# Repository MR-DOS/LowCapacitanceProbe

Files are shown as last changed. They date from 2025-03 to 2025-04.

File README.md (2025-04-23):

# LowCapacitanceProbe

## THIS DESIGN IS STILL UNDER CONSTRUCTION, ANY EXPORTED DATA ARE NON-FINAL AND ARE LIKELY NOT TO WORK. DO NOT ATTEMPT TO BUILD THIS DEVICE UNTIL THIS NOTICE DISAPPEARS! ALL IMAGES ARE PLACEHOLDERS AND MAY NOT FULLY REPRESENT THE REAL DEVICE AND MAY BE OUT OF SYNC WITH THE DESIGN DATA!

## USABLE DATA WILL BE PRESENT IN RELEASES TAB.

## 1+ GHz AC Probe with low input capacitance (less than 1 pF, hopefully)

2 dB flatness should be approx. 1.6 GHz, 3 dB flatness should be about 2.1 GHz, 6 dB flatness should be about 3.3 GHz. Design needs to be verified in reality (simulation is likely over-optimistic). In-band flatness should be better than 0.2 dB. Lower 6 dB corner should be at about 30 kHz while 3 dB corner is at about 50 kHz. The design should have fairly low noise, at least above 1 MHz.

Drawn in KiCAD 9.0.x, simulated in LTspice 17.x / 24.x.

## Expected issues

* Large noise at < 1 MHz due to thermal noise of 1M bias resistor
* Incorrect impedance of 50R traces
* Incorrect output impedance
* Possible instability of BF998 / spectrum peaking
* Bad linearity, especially due to use of varactor and resistor instead of current sink in source of BF998
* Large variance of parameters due to use of BF998

## Known issues which will be present

* No box yet (has to be covered in conductive material)
* Usage of obsolete part which is difficult to obtain (BF998)
* Component values not tried, will be suboptimal
* Varactor will probably need to be changed
* Needed manual calibration using a VNA and some tools
* Potentiometers not delinearised yet

## Board images (rendered)

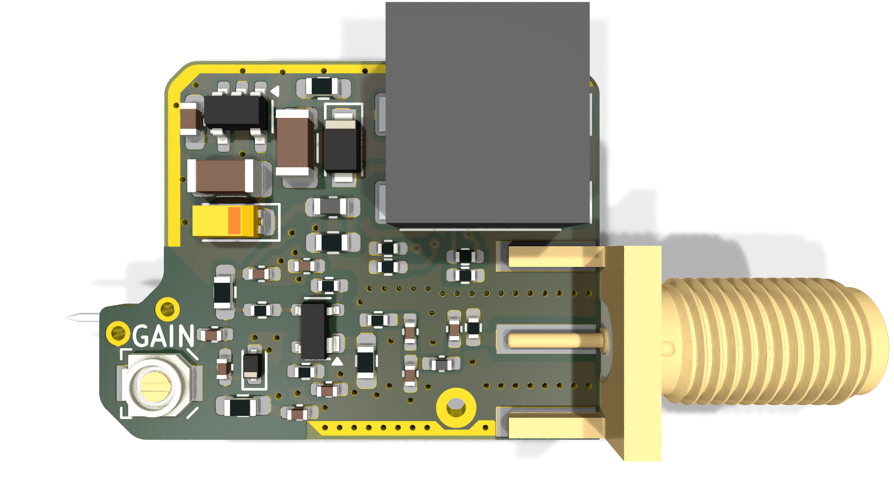
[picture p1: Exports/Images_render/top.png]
Board image TOP


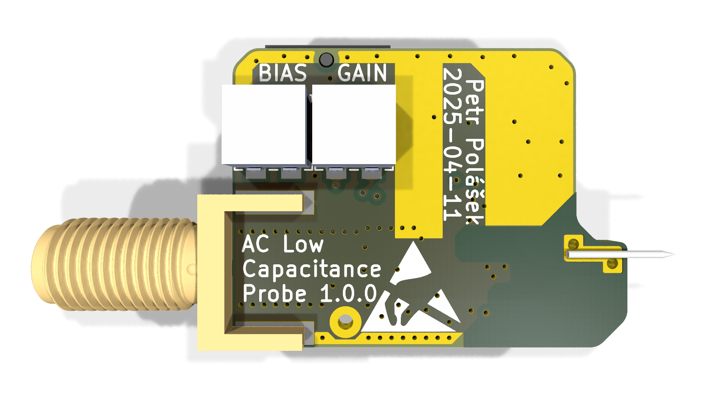
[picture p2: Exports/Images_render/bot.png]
Board image BOT


## Live on-line project browser

[KiCanvas project viewer, disable layer Dwgs.User, view is not 1:1 with KiCAD](https://kicanvas.org/?github=https%3A%2F%2Fgithub.com%2FMR-DOS%2FLowCapacitanceProbe%2Ftree%2Fmain)

## Schematic

[Schematic SVG](https://github.com/MR-DOS/LowCapacitanceProbe/raw/main/Exports/Schematic/LowCapacitanceProbe.svg)

[Schematic PDF](https://github.com/MR-DOS/LowCapacitanceProbe/raw/main/Exports/Schematic/LowCapacitanceProbe.pdf)

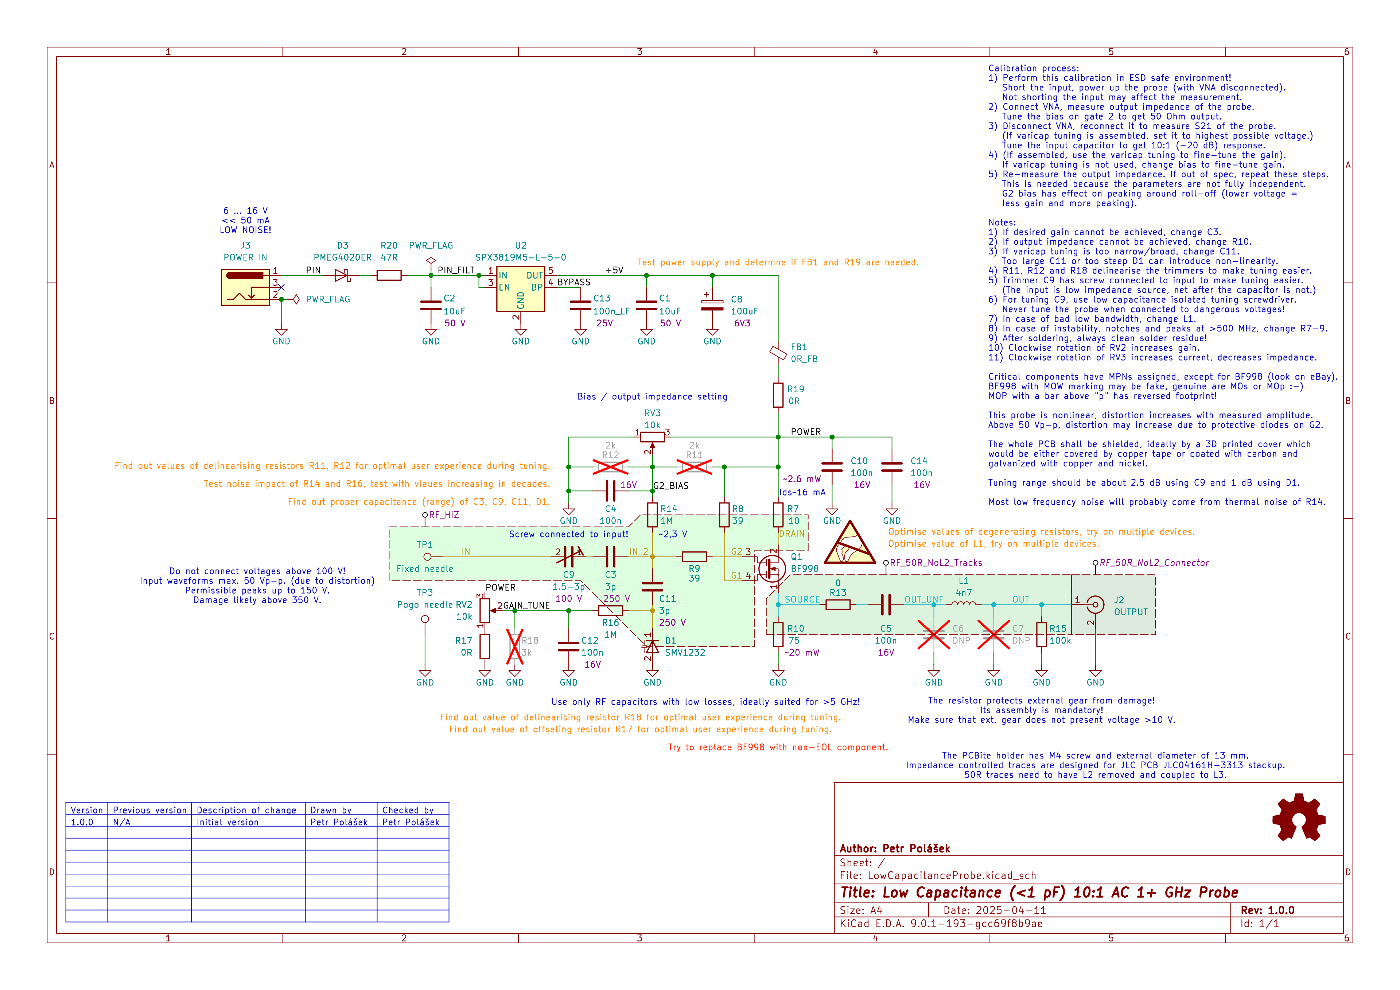
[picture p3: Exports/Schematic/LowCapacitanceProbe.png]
Schematic PNG, decent resolution


## PCB drawing image

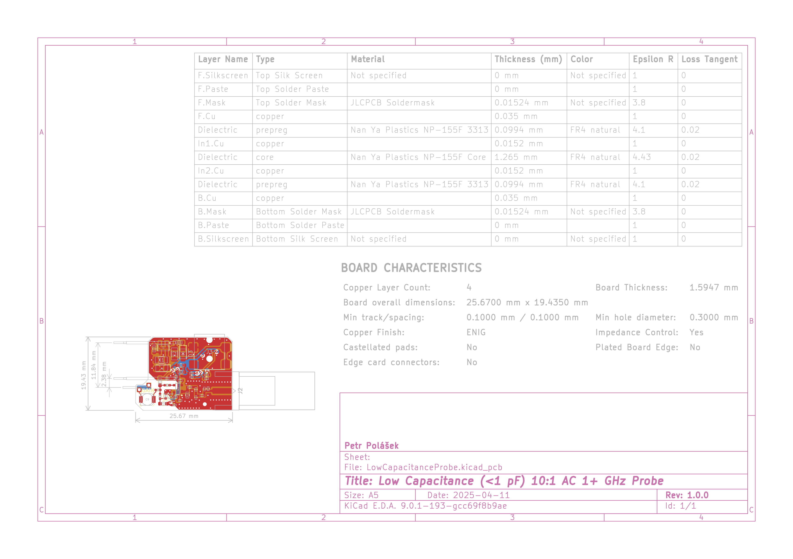
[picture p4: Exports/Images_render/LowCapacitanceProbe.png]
PCB drawing image


## 3D models

[STEP with solder mask, pads and copper fills (save to view)](https://github.com/MR-DOS/LowCapacitanceProbe/raw/main/Exports/3D/board.step)

[Simplified STEP (save to view)](https://github.com/MR-DOS/LowCapacitanceProbe/raw/main/Exports/3D/simplified/simplified.step)

## Board Shape

[DXF with board shape (save to view)](https://github.com/MR-DOS/LowCapacitanceProbe/raw/main/Exports/DXF/LowCapacitanceProbe-Edge_Cuts.dxf)

## Gerbers for production

[Zipped Gerbers](https://github.com/MR-DOS/LowCapacitanceProbe/raw/main/Exports/Gerbers/ZIP/LowCapacitanceProbe_v1.0.0.zip)

[Non-zipped Gerbers](https://github.com/MR-DOS/LowCapacitanceProbe/raw/main/Exports/Gerbers/)

## BOM

[Interactive BOM (save to view)](https://github.com/MR-DOS/LowCapacitanceProbe/raw/main/Exports/BOM/LowCapacitanceProbe_Interactive_BOM.html)

[CSV BOM (save to view)](https://github.com/MR-DOS/LowCapacitanceProbe/raw/main/Exports/BOM/LowCapacitanceProbe.csv)

## Jobset for exporting data

Use [this jobset (download it to view)](https://github.com/MR-DOS/LowCapacitanceProbe/raw/main/Outputs.kicad_jobset) for your designs, it is somewhat tested and should produce usable data. You can recreate all exports present in this repo using it.

## Simulation

[Simulation comparing this design and the FETProbe_V2 design (download to view)](https://github.com/MR-DOS/LowCapacitanceProbe/raw/main/Simulation/probe.asc) which works in LTspice 17.x and LTspice 24.x. Please note that you HAVE TO use alternate solver instead of normal solver (Tools -> Control Panel -> SPICE -> Engine -> Solver). The normal solver is faster, but has some stability issues and returns "hairy" traces of simulated gain which cannot be explained from electrical/physical standpoint.

## Sources for this design

Forked from [FETProbe_V2](https://github.com/makerprobe/FETProbe_V2) by makerprobe which is an improved fork of crteensy's [FETProbe_tiny](https://github.com/crteensy/FETProbe_tiny). Some ideas are taken from the FETProbe_V2, but most of the core design was changed to allow precise gain tuning, also the original design was suffering from being near stability threshold (and thus probably required the "spike filter").

The probe is also somewhat similar to my older [E-field probe](https://hackaday.io/project/169611-simple-e-field-probe) (which was just an unfinished toy for sniffing around circuits contactless) which is older than crteensy's FETProbe, but used G1 instead of G2 of BF998.

The need for stabilising resistors was found in another, even older project of mine, the [cheap TDR](https://github.com/MR-DOS/TDR_diploma_thesis). BF998 in source follower mode is prone to oscillation, especially when high impedance of capacitive characteristic is connected to its input.

## Intention of this design

First of all - I wanted to try the new KiCAD 8 and 9. It is also a development tool to make and tune a reusable jobset, design rules and checklist for checking validity of design (will be published later).

This project will try to make some RF optimalizations, usability improvements as well as (maybe) ability to use higher frequency transistor CF-739. However, there is no simulation model for CF-739, so it will have to be optimised empirically (and manually). Also, it is discontinued (like the BF998) and hard to obtain, rendering it unusable for making more than a few pieces of this probe.

Another path for improvement is to try using a JFET whch is still in production (J3xx or 2N439x).

Ability to tune the device (gain, output impedance) will be made to allow precise operation without fiddling with replacing components.

## Plans for next versions

A JFET version is planned to be tested if a JFET can replace the BF998. Even though the BF998 are not difficult to obtain, they are obsolete.
JFET simulation [can be found here (download to view)](https://github.com/MR-DOS/LowCapacitanceProbe/raw/main/Simulation/probe_jfet.asc).

Several JFETs [were found to be similar](https://github.com/MR-DOS/LowCapacitanceProbe/raw/main/Simulation/jfet_sim_notes.txt) to the BF998 in simulation. However they need to be tested.

## Other notes

If you want to figure out where your BF998 was produced, [look here](http://sp7pki.iq24.pl/default.asp?grupa=3536&temat=449565).

Beware of buying BF998R, those have reversed pinout. Also do not buy ones marked as "WMO", those are also reversed AND in smaller package than normal. ("MOW" are OK)

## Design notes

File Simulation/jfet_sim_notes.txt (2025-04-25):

Sim notes:
2N4392 - slight problems getting to -20 dB
2N4393 - better by ~1 dB
2N5486 - -20 dB will likely need larger capacitance
J113	 - with difficulties -21 dB
LS5912C - -20 dB will likely need larger capacitance
LS5912 - maybe slightly better
LS5911 - similar
LS845  - -20 dB will likely need larger capacitance
PN4119 - slight problems getting to -20 dB
PN4118/7 - probably better
PN4393 - similar to 2N4393
SST440 - larger capacity needed

Winners:
PN4118 - slightly expensive, 3 pF
PN4117 - like 4118, lower current, 3 pF
2N4393 - THT only, 14 pF
PN4393 - THT only, 14 pF
LS5912 - expensive, dual, 5 pF

Ordered:
106-SMP4118A		2x
106-SMP4393			2x
610-CMPF4393TR-TIN	2x
863-MMBF4393LT1G		10x (cheap)
610-CMPF4392		2x
863-MMBF4392LT1G		10x (cheap)
512-MMBF4117		10x (cheap)

Further notes:
Models of JFETs now downloaded from here
https://www.interfet.com/jfet-spice-models/
https://www.interfet.com/jfet-datasheets/standard.jft
2N3970/1	NSC		-24 dB
2N5105	NSC		-24 dB
2N4391	Linear Sys	-22 dB
2N4856A	NSC		-21 dB
2N5486	Siliconix	-21 dB
2N4392/3	Linear Sys	-20 dB
PN4117/8	Linear Sys	-20 dB
PN4393	Linear Sys	-20 dB
PN4119	Linear Sys	-19.5 dB
2N4857A/8A	NSC		-19.5 dB
2N4860A	NSC		-19.5 dB
2N4861A	NSC		-19 dB
2N3824	InterFET	-18 dB
SSTJ212	Linear Sys	-10 dB

BF998 optimisation A:
G1	10
G2	56
D	42
L	4n7
BW1dB	3.9 GHz
BW3dB	4.3 GHz
BW6db	4.8 GHz
Peak	3 GHZ, +0.5 dB
Fall	20 dB/oct	

BF998 optimisation B:
G1	22
G2	51
D	42
L	3n3
BW1dB	3.4 GHz
BW3dB	4.1 GHz
BW6db	4.8 GHz
Peak	1.4 GHz, +0.08 dB
Fall	20 dB/oct

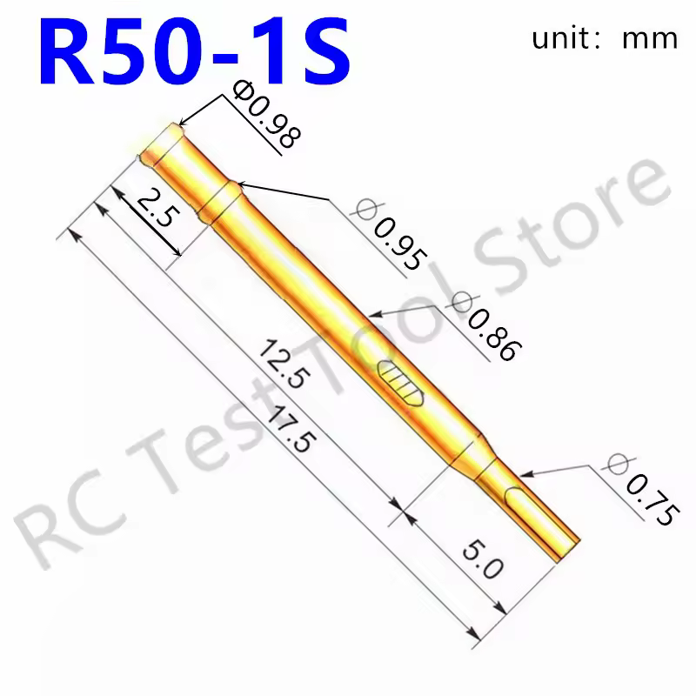
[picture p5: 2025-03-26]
Mechanical/R50-1S.png

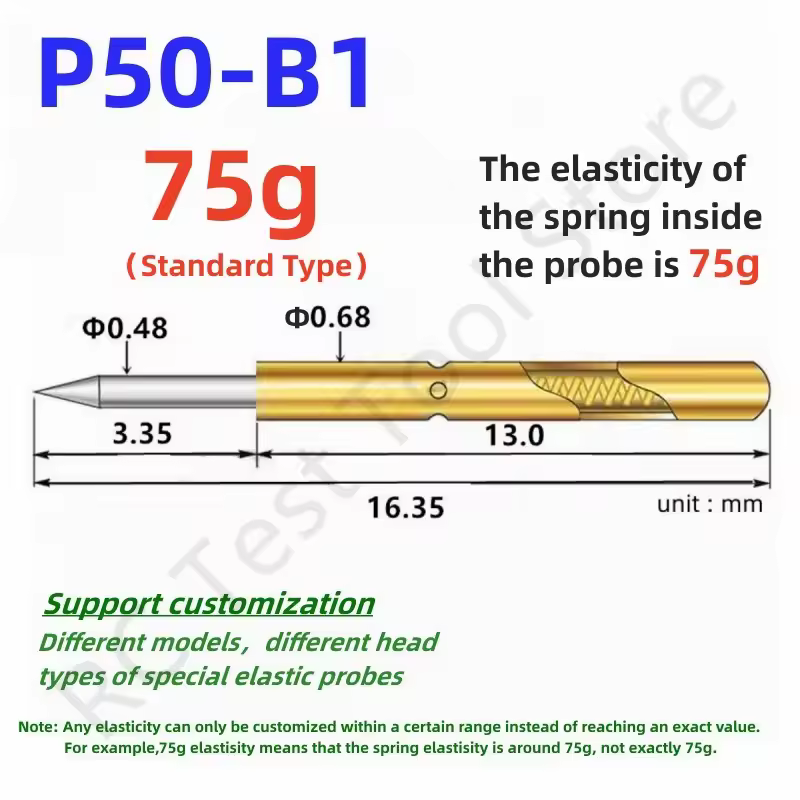
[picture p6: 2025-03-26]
Mechanical/P50-B1.png

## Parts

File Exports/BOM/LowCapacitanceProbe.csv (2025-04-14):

Reference | Value | Footprint | MPN | Mouser | Qty
C1,C2 | 10uF | Capacitor_SMD:C_1206_3216Metric | CL31A106MBHNNNE | 187-CL31A106MBHNNNE | 2
C3,C11 | 3p | Capacitor_SMD:C_0402_1005Metric_Pad0.74x0.62mm_HandSolder | 600F3R0CT250XT | 581-600F3R0CT | 2
C4,C5,C10,C12,C14 | 100n | Capacitor_SMD:C_0402_1005Metric_Pad0.74x0.62mm_HandSolder | 530L104KT16T | 581-530L104KT16T | 5
C6,C7 | DNP | Capacitor_SMD:C_0402_1005Metric_Pad0.74x0.62mm_HandSolder |  |  | 2
C8 | 100uF | Capacitor_Tantalum_SMD:CP_EIA-3216-18_Kemet-A | T55A107M6R3C0045 | 74-T55A107M6R3C0045 | 1
C9 | 1.5-3p | Capacitor_SMD:C_Trimmer_Voltronics_JR | JR030 | 768-JR030 | 1
C13 | 100n_LF | Capacitor_SMD:C_0603_1608Metric_Pad1.08x0.95mm_HandSolder |  |  | 1
D1 | SMV1232 | Diode_SMD:D_SOD-523 | SMV1231-079LF | 873-SMV1231-079LF | 1
D3 | PMEG4020ER | Diode_SMD:Nexperia_CFP3_SOD-123W | PMEG4020ER,115 | 771-PMEG4020ER115 | 1
FB1 | 0R_FB | Inductor_SMD:L_0603_1608Metric_Pad1.05x0.95mm_HandSolder |  |  | 1
J2 | OUTPUT | Connector_Coaxial:SMA_Amphenol_132289_EdgeMount | 132289 | 523-132289 | 1
J3 | POWER IN | Connector_BarrelJack:BarrelJack_Wuerth_694103107102_1.35x3.9mm | 694103107102 | 710-694103107102 | 1
L1 | 4n7 | Inductor_SMD:L_0402_1005Metric_Pad0.77x0.64mm_HandSolder | LQG15HS4N7B02D | 81-LQG15HS4N7B02D | 1
Q1 | BF998 | Package_TO_SOT_SMD:SOT-143 |  |  | 1
R7 | 10 | Resistor_SMD:R_0402_1005Metric_Pad0.72x0.64mm_HandSolder |  |  | 1
R8,R9 | 39 | Resistor_SMD:R_0402_1005Metric_Pad0.72x0.64mm_HandSolder |  |  | 2
R10 | 75 | Resistor_SMD:R_0603_1608Metric_Pad0.98x0.95mm_HandSolder |  |  | 1
R11,R12 | 2k | Resistor_SMD:R_0402_1005Metric_Pad0.72x0.64mm_HandSolder |  |  | 2
R13 | 0 | Resistor_SMD:R_0402_1005Metric_Pad0.72x0.64mm_HandSolder |  |  | 1
R14,R16 | 1M | Resistor_SMD:R_0603_1608Metric_Pad0.98x0.95mm_HandSolder |  |  | 2
R15 | 100k | Resistor_SMD:R_0402_1005Metric_Pad0.72x0.64mm_HandSolder |  |  | 1
R17,R19 | 0R | Resistor_SMD:R_0402_1005Metric_Pad0.72x0.64mm_HandSolder,Resistor_SMD:R_0603_1608Metric_Pad0.98x0.95mm_HandSolder |  |  | 2
R18 | 3k | Resistor_SMD:R_0402_1005Metric_Pad0.72x0.64mm_HandSolder |  |  | 1
R20 | 47R | Resistor_SMD:R_0603_1608Metric_Pad0.98x0.95mm_HandSolder |  |  | 1
RV2,RV3 | 10k | Potentiometer_SMD:Potentiometer_Bourns_3214J_Horizontal | 3214J-1-103E | 652-3214J-1-103E | 2
U2 | SPX3819M5-L-5-0 | Package_TO_SOT_SMD:SOT-23-5 | SPX3819M5-L-5-0/TR | 701-SPX3819M5-L-50TR | 1

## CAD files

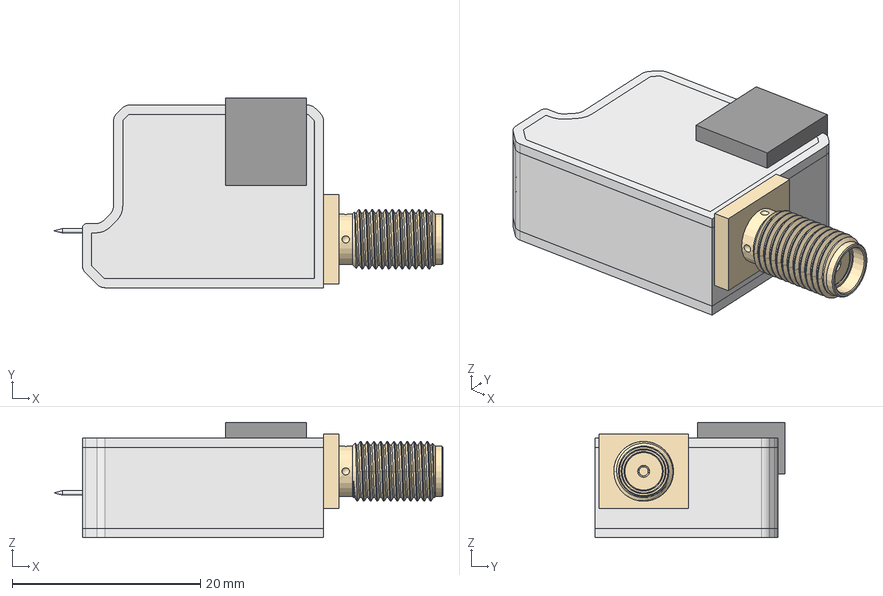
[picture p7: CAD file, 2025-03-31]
Mechanical/Assembly.FCStd
41.4 x 20.2 x 12.3 mm
SMA_Amphenol_132289_EdgeMount
C_0603_1608Metric
C_1206_3216Metric
3214J-1-103E
SOT-143
R_0402_1005Metric
CP_EIA-3216-18_Kemet-A
board 4.8.1
board 4.8.002
board 4.8.003
board 4.8.004
C_0402_1005Metric
C_0402_1005Metric001
R_0603_1608Metric
R_0603_1608Metric001
L_0402_1005Metric
R_0402_1005Metric001
L_0603_1608Metric
C_0402_1005Metric002
C_0402_1005Metric003
SOT-23-5
C_0402_1005Metric004
C_0402_1005Metric005
C_1206_3216Metric001
R_0402_1005Metric002
R_0603_1608Metric002
R_0603_1608Metric003
C_0402_1005Metric006
C_0402_1005Metric007
R_0402_1005Metric003
R_0402_1005Metric004
R_0402_1005Metric005
R_0402_1005Metric006
C_0402_1005Metric008
C_Trimmer_Voltronics_JR
D_SOD-523
Pins
Pins001
Pins002
Pins003
Lugs
Lugs001
Lugs003
Lugs004
R_0603_1608Metric004
R_0402_1005Metric007
R_0402_1005Metric008
3214J-1-103E001
P50-B1 needle
LowCapacitanceProbe_copper
LowCapacitanceProbe_copper001
LowCapacitanceProbe_copper002
LowCapacitanceProbe_copper003
LowCapacitanceProbe_copper004
LowCapacitanceProbe_copper005
LowCapacitanceProbe_copper006
LowCapacitanceProbe_copper007
LowCapacitanceProbe_copper008
LowCapacitanceProbe_copper009
LowCapacitanceProbe_copper010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

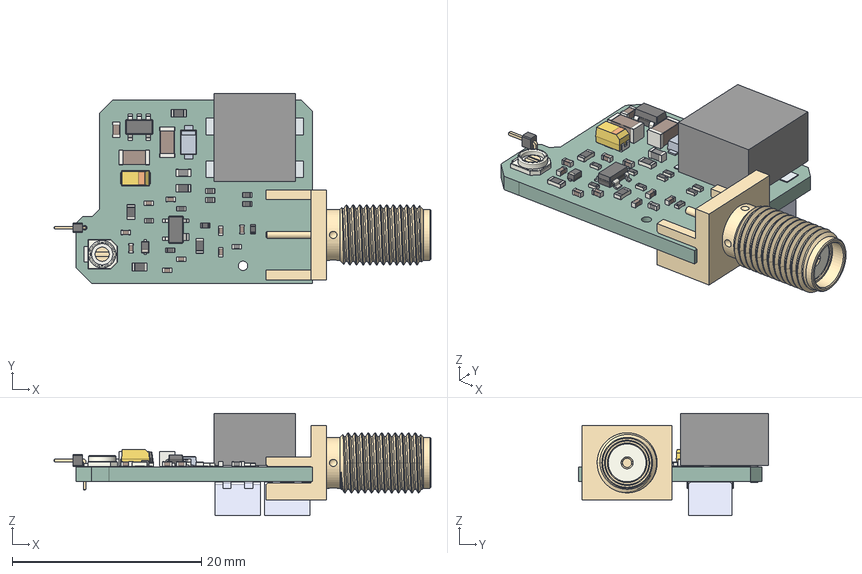
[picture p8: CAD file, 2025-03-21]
Exports/3D/board.step
39.9 x 20.1 x 10.8 mm
SMA_Amphenol_132289_EdgeMount
SOT-143
R_0402_1005Metric x 9
CP_EIA-3216-18_Kemet-A
board 2.5.1
C_0402_1005Metric x 9
R_0603_1608Metric x 5
C_0603_1608Metric
L_0402_1005Metric
C_1206_3216Metric x 2
L_0603_1608Metric
PinHeader_1x01_P1.00mm_Horizontal
SOT-23-5
C_Trimmer_Voltronics_JR
D_SOD-523
Pins
Lugs x 2
3214J-1-103E x 2
LowCapacitanceProbe_PCB

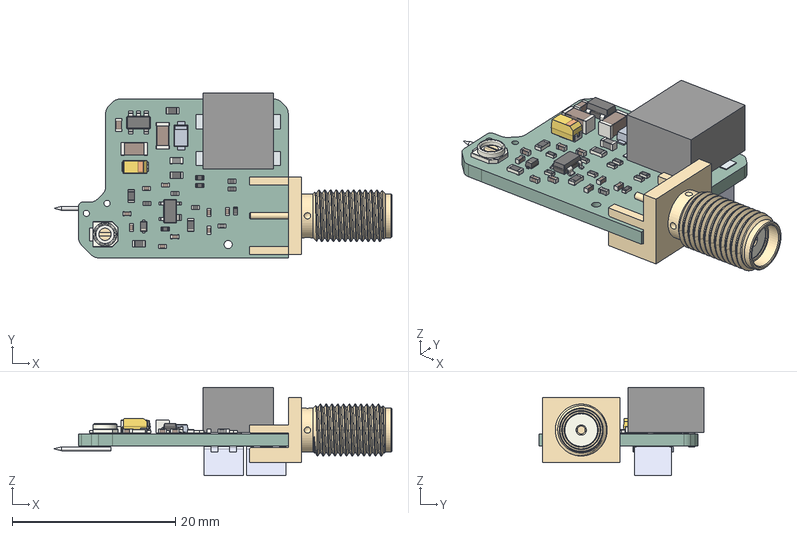
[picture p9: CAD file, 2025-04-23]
Exports/3D/simplified/simplified.step
41.4 x 20.2 x 10.8 mm
SOT-143
R_0402_1005Metric x 9
SMA_Amphenol_132289_EdgeMount
CP_EIA-3216-18_Kemet-A
simplified 2.5.1
C_0402_1005Metric x 9
R_0603_1608Metric x 5
C_0603_1608Metric
L_0402_1005Metric
C_1206_3216Metric x 2
L_0603_1608Metric
SOT-23-5
C_Trimmer_Voltronics_JR
D_SOD-523
Pins
Lugs x 2
3214J-1-103E x 2
P50-B1 needle
LowCapacitanceProbe_copper
LowCapacitanceProbe_PCB

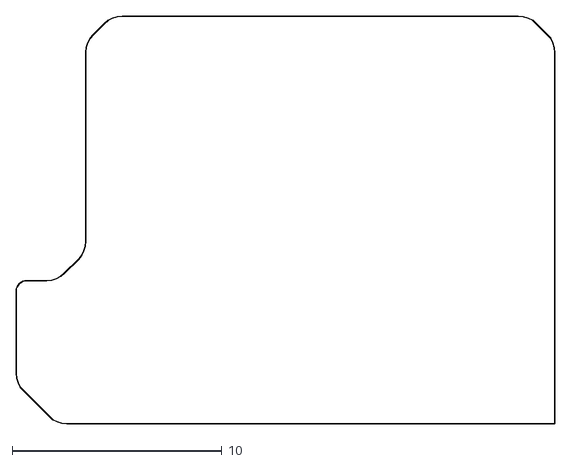
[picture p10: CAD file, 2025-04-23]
Exports/DXF/LowCapacitanceProbe-Edge_Cuts.dxf
25.7 x 19.4

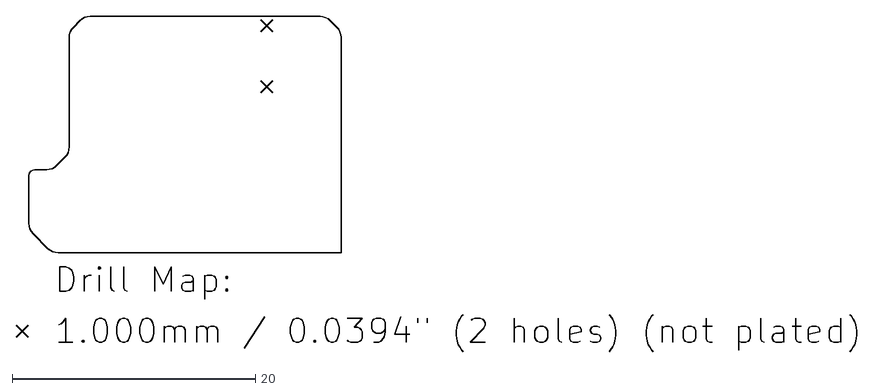
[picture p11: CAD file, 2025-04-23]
Exports/Gerbers/LowCapacitanceProbe-NPTH-drl_map.dxf
69.1 x 27.6

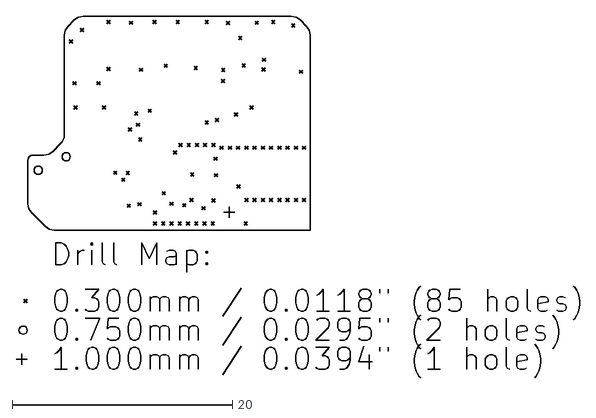
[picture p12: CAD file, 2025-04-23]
Exports/Gerbers/LowCapacitanceProbe-PTH-drl_map.dxf
51.2 x 32.8

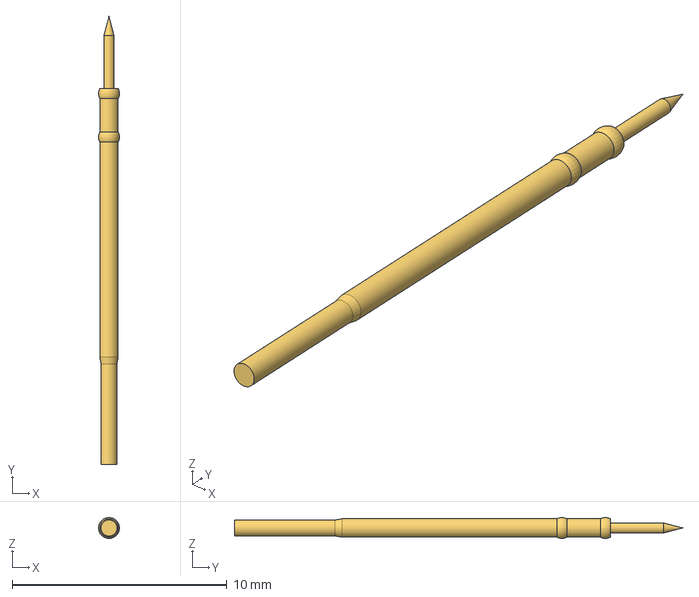
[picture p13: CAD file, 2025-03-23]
Mechanical/P50-B1 + R50-1S.step
0.979 x 20.9 x 0.978 mm

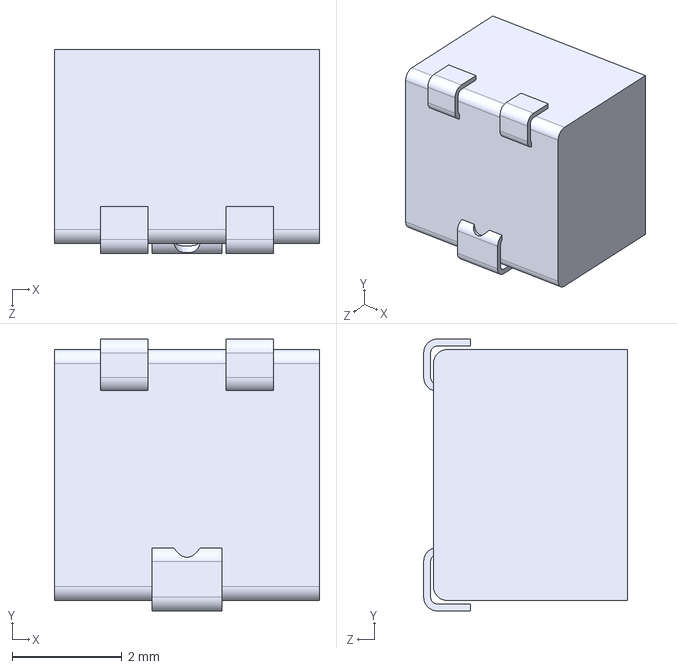
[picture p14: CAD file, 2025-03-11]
Footprint_models/3214J-1-103E.stp
4.83 x 4.95 x 3.71 mm

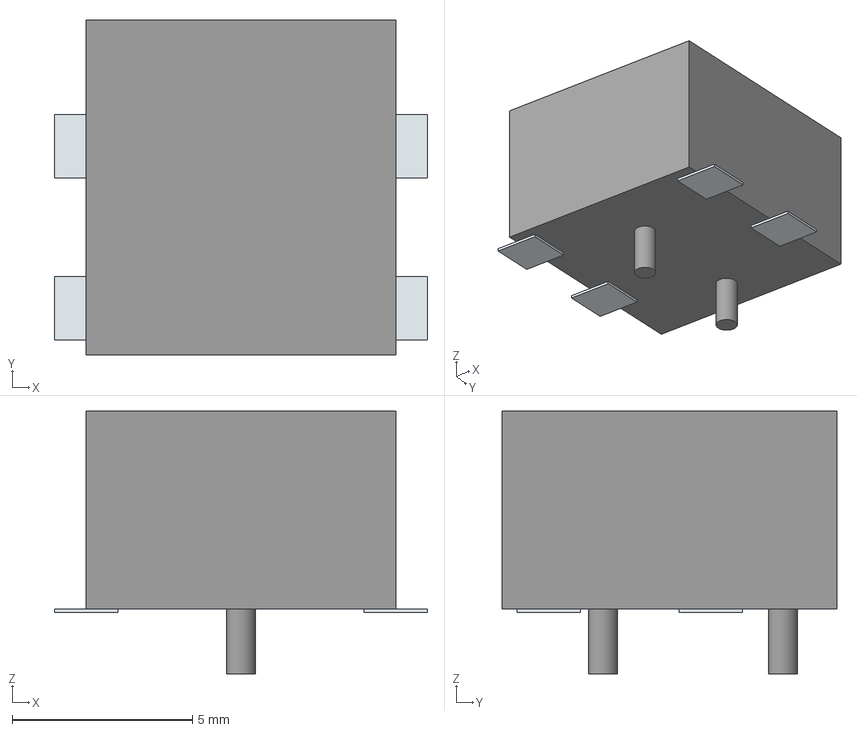
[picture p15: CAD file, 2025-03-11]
Footprint_models/694103107102.stp
10.4 x 9.30 x 7.30 mm
Pins
Lugs x 2

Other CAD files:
Exports/3D/simplified/.step
Mechanical/P50-B1 + R50-1S.FCStd

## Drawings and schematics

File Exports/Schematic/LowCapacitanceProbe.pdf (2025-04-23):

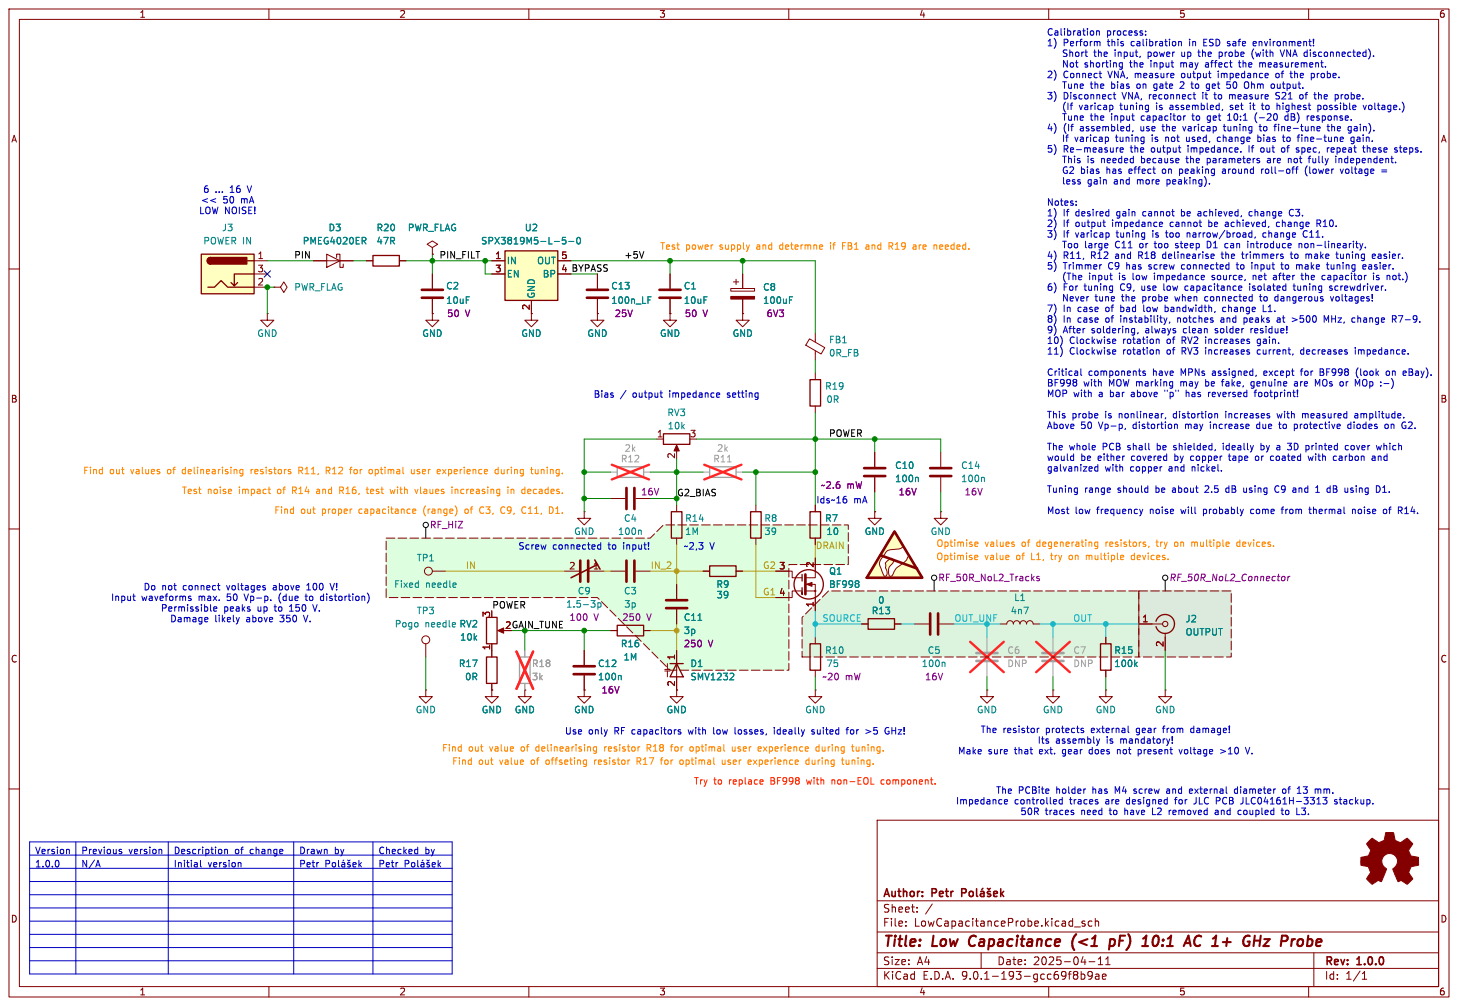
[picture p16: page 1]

Its assembly is mandatory! Make sure that ext. gear does not present voltage >10 V.

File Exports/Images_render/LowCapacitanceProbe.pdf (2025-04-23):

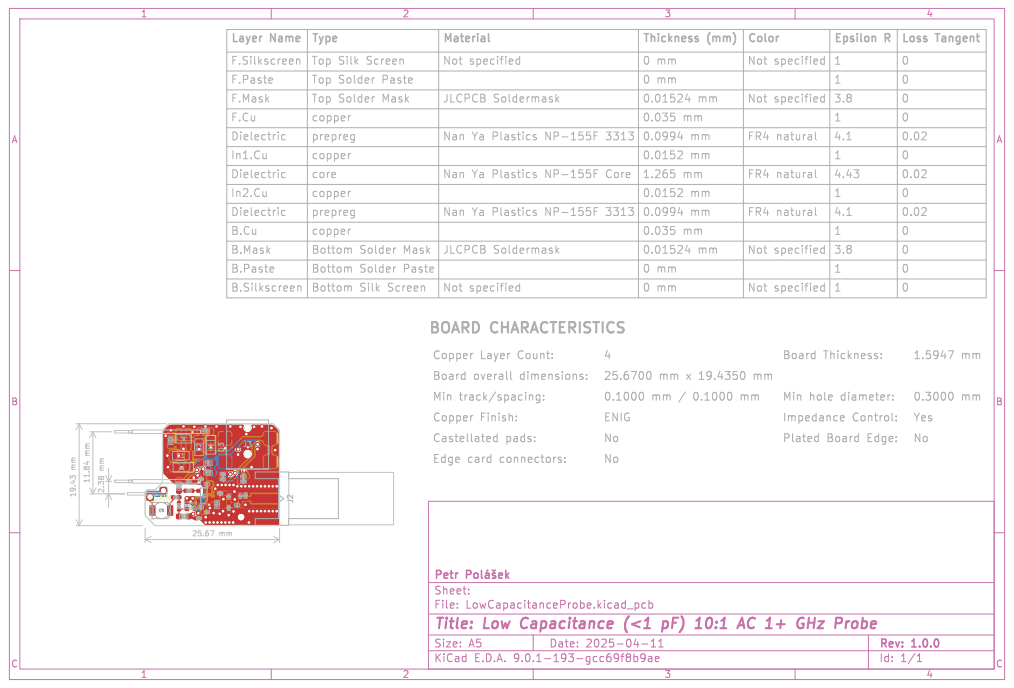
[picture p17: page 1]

Thickness 0.01524 mm | (mm) copper | FR4 natural Not specified Dielectric | 3.8 | 0.02

Bottom Solder Mask copper F.Paste | | 0.035 mm | | Color FR4 natural B.Paste | 1 | 0

Loss Tangent 0 0

In1.Cu | Top Solder Mask | | | 0.0152 mm | | 1 1 | 0 BOARD CHARACTERISTICS

Top Solder Paste | | 0 mm | | 1

1 Not specified 4.1

prepreg | | Core | 0 mm 0.0994 mm | Not specified B.Silkscreen | 4.1 | 0 Nan Ya Plastics NP-155F
In2.Cu | | | | 0.0152 mm

core | | | | | | 1.265 mm

0.035 mm
0.01524 mm
0 mm | | | | 0

Bottom Silk Screen | | | | | Not specified | | 0

Copper Layer Count: | | 4 25.6700 | mm x 19.4350 | 1.5947 mm mm

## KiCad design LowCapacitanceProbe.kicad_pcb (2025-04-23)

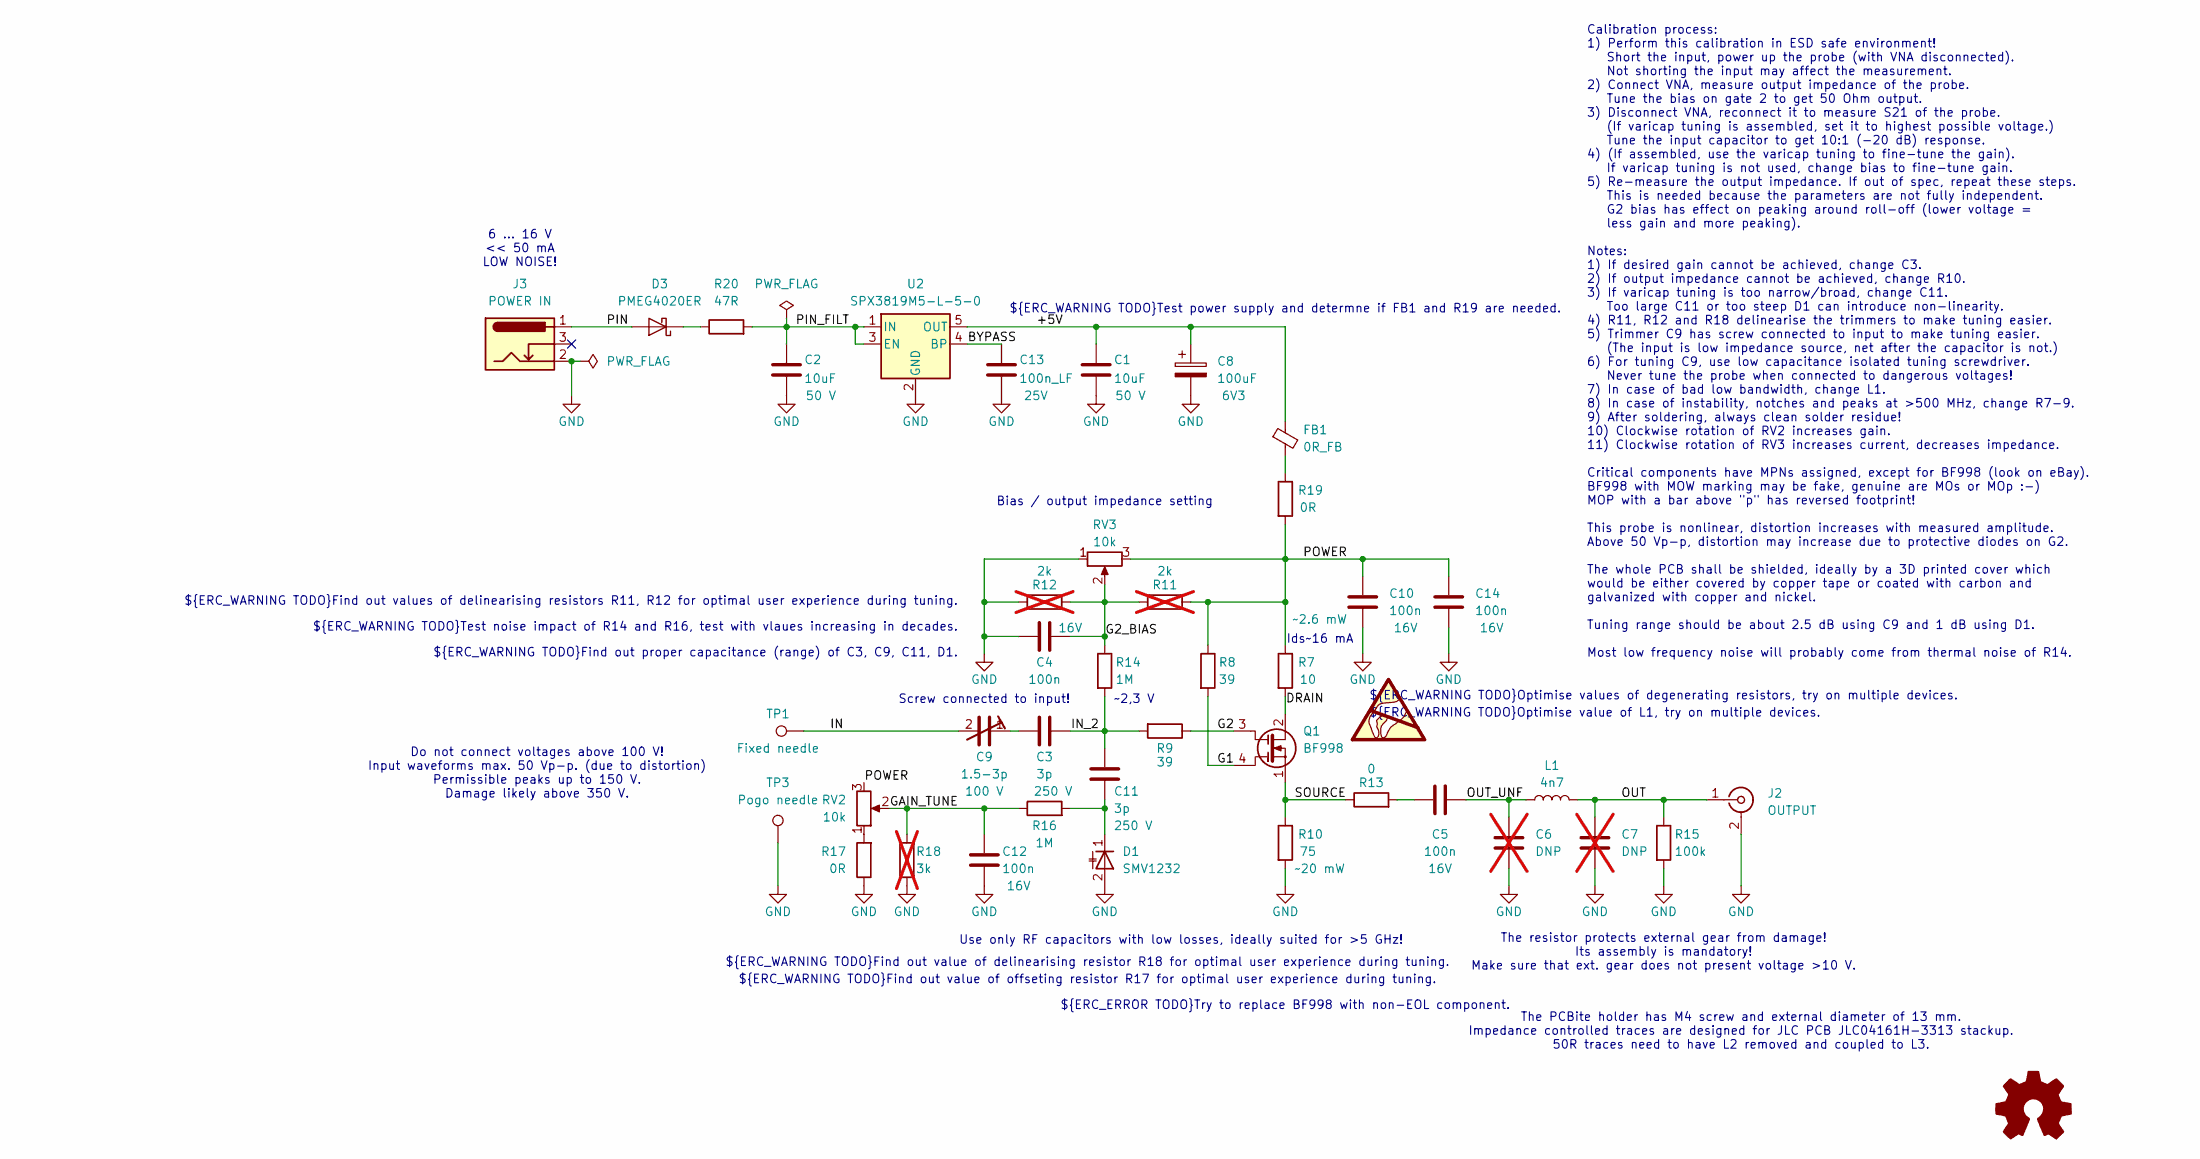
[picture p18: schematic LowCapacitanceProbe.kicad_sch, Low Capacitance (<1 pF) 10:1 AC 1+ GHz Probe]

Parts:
C1, C2: 10uF; C_1206_3216Metric; Rating 50 V; MPN CL31A106MBHNNNE; Mouser 187-CL31A106MBHNNNE
C3, C11: 3p; C_0402_1005Metric_Pad0.74x0.62mm_HandSolder; Rating 250 V; MPN 600F3R0CT250XT; Mouser 581-600F3R0CT
C4, C5, C10, C12, C14: 100n; C_0402_1005Metric_Pad0.74x0.62mm_HandSolder; Rating 16V; MPN 530L104KT16T; Mouser 581-530L104KT16T
C6, C7: DNP; C_0402_1005Metric_Pad0.74x0.62mm_HandSolder; not fitted
C8: 100uF; CP_EIA-3216-18_Kemet-A; Rating 6V3; MPN T55A107M6R3C0045; Mouser 74-T55A107M6R3C0045
C9: 1.5-3p; C_Trimmer_Voltronics_JR; Rating 100 V; MPN JR030; Mouser 768-JR030
C13: 100n_LF; C_0603_1608Metric_Pad1.08x0.95mm_HandSolder; Rating 25V
D1: SMV1232; D_SOD-523; MPN SMV1231-079LF; Mouser 873-SMV1231-079LF
D3: PMEG4020ER; Nexperia_CFP3_SOD-123W; MPN PMEG4020ER,115; Mouser 771-PMEG4020ER115
FB1: 0R_FB; L_0603_1608Metric_Pad1.05x0.95mm_HandSolder
J2: OUTPUT; SMA_Amphenol_132289_EdgeMount; MPN 132289; Mouser 523-132289
J3: POWER IN; BarrelJack_Wuerth_694103107102_1.35x3.9mm; MPN 694103107102; Mouser 710-694103107102
L1: 4n7; L_0402_1005Metric_Pad0.77x0.64mm_HandSolder; MPN LQG15HS4N7B02D; Mouser 81-LQG15HS4N7B02D
Q1: BF998; SOT-143
R7: 10; R_0402_1005Metric_Pad0.72x0.64mm_HandSolder; Rating ~2.6 mW
R8, R9: 39; R_0402_1005Metric_Pad0.72x0.64mm_HandSolder
R10: 75; R_0603_1608Metric_Pad0.98x0.95mm_HandSolder; Rating ~20 mW
R11, R12: 2k; R_0402_1005Metric_Pad0.72x0.64mm_HandSolder; not fitted
R13: 0; R_0402_1005Metric_Pad0.72x0.64mm_HandSolder
R14, R16: 1M; R_0603_1608Metric_Pad0.98x0.95mm_HandSolder
R15: 100k; R_0402_1005Metric_Pad0.72x0.64mm_HandSolder
R17: 0R; R_0402_1005Metric_Pad0.72x0.64mm_HandSolder
R18: 3k; R_0402_1005Metric_Pad0.72x0.64mm_HandSolder; not fitted
R19: 0R; R_0603_1608Metric_Pad0.98x0.95mm_HandSolder
R20: 47R; R_0603_1608Metric_Pad0.98x0.95mm_HandSolder
RV2, RV3: 10k; Potentiometer_Bourns_3214J_Horizontal; MPN 3214J-1-103E; Mouser 652-3214J-1-103E
SYM1: Logo_Open_Hardware_Small; OSHW-Logo2_7.3x6mm_SilkScreen
SYM3: SYM_ESD_Large; ESD-Logo_6.6x6mm_SilkScreen
TP1: Fixed needle; P50-B1_needle
TP3: Pogo needle; TestPoint_THTPad_D2.0mm_Drill1.0mm
U2: SPX3819M5-L-5-0; SOT-23-5; MPN SPX3819M5-L-5-0/TR; Mouser 701-SPX3819M5-L-50TR

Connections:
/+5V: C1.2, C8.1, FB1.1, U2.5 (OUT)
/BYPASS: C13.2, U2.4 (BP)
/DRAIN: Q1.2 (D), R7.2
/G1: Q1.4 (G2), R8.2
/G2: Q1.3 (G1), R9.1
/G2_BIAS: C4.1, R11.1, R12.2, R14.1, RV3.2
/GAIN_TUNE: C12.2, R16.1, R18.2, RV2.2
/IN: C9.2, TP1.1
/IN_2: C3.2, C11.2, R9.2, R14.2
/OUT: C7.2, J2.1 (In), L1.2, R15.1
/OUT_UNF: C5.1, C6.2, L1.1
/PIN: D3.2 (A), J3.1
/PIN_FILT: C2.2, R20.2, U2.1 (IN), U2.3 (EN)
/POWER: C10.2, C14.2, R7.1, R8.1, R11.2, R19.2, RV2.3, RV3.3
/SOURCE: Q1.1 (S), R10.1, R13.1
GND: C1.1, C2.1, C4.2, C6.1, C7.1, C8.2, C10.1, C12.1, C13.1, C14.1, D1.2 (A), J2.2 (Ext), J3.2, R10.2, R12.1, R15.2, R17.1, R18.1, RV3.1, TP3.1, U2.2 (GND)
unnamed: C3.1, C9.1
unnamed: C5.2, R13.2
unnamed: C11.1, D1.1 (K), R16.2
unnamed: D3.1 (K), R20.1
unnamed: FB1.2, R19.1
unnamed: R17.2, RV2.1

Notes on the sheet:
${ERC_WARNING TODO}Test noise impact of R14 and R16, test with vlaues increasing in decades.
Do not connect voltages above 100 V! Input waveforms max. 50 Vp-p. (due to distortion) Permissible peaks up to 150 V. Damage likely above 350 V.
${ERC_WARNING TODO}Optimise value of L1, try on multiple devices.
Use only RF capacitors with low losses, ideally suited for >5 GHz!
${ERC_WARNING TODO}Find out proper capacitance (range) of C3, C9, C11, D1.
${ERC_WARNING TODO}Find out value of offseting resistor R17 for optimal user experience during tuning.
${ERC_WARNING TODO}Find out values of delinearising resistors R11, R12 for optimal user experience during tuning.
~2,3 V
The resistor protects external gear from damage! Its assembly is mandatory! Make sure that ext. gear does not present voltage >10 V.
Bias / output impedance setting
Calibration process: 1) Perform this calibration in ESD safe environment! Short the input, power up the probe (with VNA disconnected). Not shorting the input may affect the measurement. 2) Connect VNA, measure output impedance of the probe. Tune the bias on gate 2 to get 50 Ohm output. 3) Disconnec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
${ERC_ERROR TODO}Try to replace BF998 with non-EOL component.
${ERC_WARNING TODO}Optimise values of degenerating resistors, try on multiple devices.
${ERC_WARNING TODO}Find out value of delinearising resistor R18 for optimal user experience during tuning.
Screw connected to input!
Ids~16 mA
${ERC_WARNING TODO}Test power supply and determne if FB1 and R19 are needed.
6 ... 16 V << 50 mA LOW NOISE!
The PCBite holder has M4 screw and external diameter of 13 mm. Impedance controlled traces are designed for JLC PCB JLC04161H-3313 stackup. 50R traces need to have L2 removed and coupled to L3.

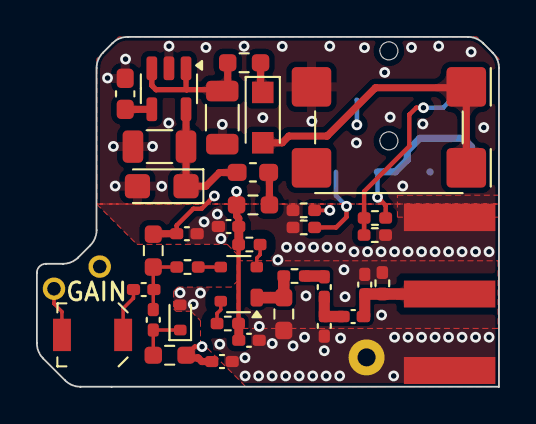
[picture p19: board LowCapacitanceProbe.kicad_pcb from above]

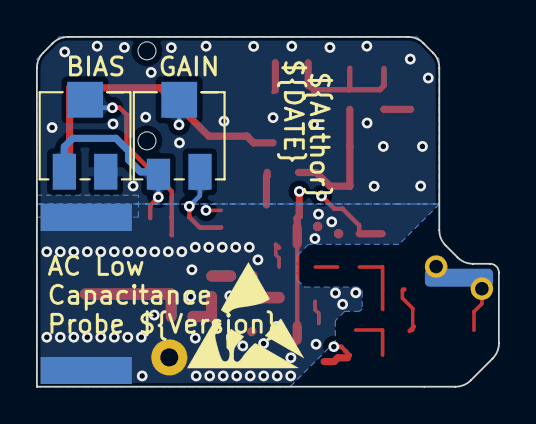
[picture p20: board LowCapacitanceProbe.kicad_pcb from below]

Board: 4 copper layers, 25.7 x 19.4 mm, 41 parts (4 on the bottom side), 22 nets.

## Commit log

2025-02-24 Added simulation which should solve instabilities at high frequencies as well as unmatched output impedance (was about 30 Ohm).
2025-02-25 Finished simulation, in simulation the probe was extended from 1.3 GHz to 1.68 GHz [2 dB] (or from 1.87 to 3.3 GHz [6 dB]). Flatness was greatly improved, roll-off now nearly approximates first order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
    [LowCapacitanceProbe.kicad_pcb, LowCapacitanceProbe.kicad_sch]
2025-02-25 Slight fixes to simulation, started modifying schematics.
    [LowCapacitanceProbe.kicad_sch]
2025-02-26 Added more possibilities for tuning gain, added delinearization networks for easier fine-tuning, increased power supply voltage, fixed BF998 symbol. Added simulation of delinearization networks.
    [LowCapacitanceProbe.kicad_sch]
2025-02-28 Added calibration notes, fixed delinearization for gate bias
    [LowCapacitanceProbe.kicad_sch]
2025-02-28 Added footprints to all components, added MPNs and Mouser numbers to critical components. Added some notes.
    [LowCapacitanceProbe.kicad_sch]
2025-02-28 refresh after save
    [LowCapacitanceProbe.kicad_sch]
2025-02-28 Changed output connector to SMA, changed diode for more common one.
    [LowCapacitanceProbe.kicad_sch]
2025-03-01 Reduced peak current during connection of power, replaced LDO from adjustable version by 5V, lowered noise of LDO.
    [LowCapacitanceProbe.kicad_sch]
2025-03-01 Added net labels, synchronised PCB with SCH, grouped all elements.
    [LowCapacitanceProbe.kicad_pcb, LowCapacitanceProbe.kicad_sch]
2025-03-01 Slight fixes, simulation modified for varicap analysis and noise analysis, started routing of PCB.
    [LowCapacitanceProbe.kicad_pcb, LowCapacitanceProbe.kicad_sch]
2025-03-02 Replaced trimmers by smaller SMT types, continued routing.
    [LowCapacitanceProbe.kicad_pcb, LowCapacitanceProbe.kicad_sch]
2025-03-03 Added mounting point for PCBite holder (M4 nut).
    [LowCapacitanceProbe.kicad_pcb, LowCapacitanceProbe.kicad_sch]
2025-03-03 Continued routing, modifications for better usability.
    [LowCapacitanceProbe.kicad_pcb, LowCapacitanceProbe.kicad_sch]
2025-03-07 Synchronisation of computers, some tiny changes to simulation.
    [LowCapacitanceProbe.kicad_pcb]
2025-03-10 Continued routing, replaced power connector.
    [LowCapacitanceProbe.kicad_pcb, LowCapacitanceProbe.kicad_sch]
2025-03-11 Replaced trimmers, added 3D models, continued routing and placing.
    [3214J-1-103E.stp, 694103107102.stp, LowCapacitanceProbe.kicad_pcb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]
2025-03-12 Further work on routing, change to 4 layers is imminent.
    [LowCapacitanceProbe.kicad_pcb, LowCapacitanceProbe.kicad_sch]
2025-03-15 More routing
    [LowCapacitanceProbe.kicad_pcb]
2025-03-18 Some more routing, modified outjob.
    [LowCapacitanceProbe.kicad_pcb, board.step]
2025-03-20 Additional routing, finalizing PCB shape.
    [LowCapacitanceProbe.kicad_pcb]
2025-03-21 Started adding JLCPCB rules, board rules, net classes, component classes, custom DRC rules, finishing board, RF traces for JLCPCB 4L 3313, unmasked outline for conductive case etc.
    [LowCapacitanceProbe.kicad_pcb, LowCapacitanceProbe.kicad_sch]
2025-03-21 Refreshed exports
    [board.step]
2025-03-23 Added footprint and model of P50 broken needle and whole pogo with sleeve. Finalizing shape and ground contacts.
    [LowCapacitanceProbe.kicad_pcb, LowCapacitanceProbe.kicad_sch, P50-B1 + R50-1S.FCStd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]
2025-03-26 Some macdinking, review/checklist in progress.
    [LowCapacitanceProbe.kicad_pcb, LowCapacitanceProbe.kicad_sch]
2025-03-31 Final finishing touches, checking.
    [Assembly.FCStd, LowCapacitanceProbe-Edge_Cuts.dxf, LowCapacitanceProbe.kicad_pcb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]
2025-04-08 Finishing PCB, toying with jobset, exporting data.
    [.step, LowCapacitanceProbe-Edge_Cuts.dxf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]
2025-04-08 Fixed images
    [LowCapacitanceProbe.kicad_pcb]
2025-04-10 Finishing data, completing jobset, ready to send to JLC PCB.
    [.step, LowCapacitanceProbe-Edge_Cuts.dxf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]
2025-04-11 Fixed some RF traces, copper fills, added some teardrops.
    [.step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]
2025-04-11 Some more fixes to GND fill, added board stackup and board characteristics.
    [.step, LowCapacitanceProbe-Edge_Cuts.dxf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]
2025-04-14 Fiddling with jobset, updating readme.
    [LowCapacitanceProbe-B_Cu.gbl, LowCapacitanceProbe-B_Mask.gbs, LowCapacitanceProbe-B_Paste.gbp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]
2025-04-14 Fixed BOM in gitignore, added KiCanvas link.
    [LowCapacitanceProbe.csv]
2025-04-14 Added PCB drawing export to jobset + data.
    [LowCapacitanceProbe.kicad_pcb]
2025-04-23 Fixed jobset to use relative paths everywhere
    [LowCapacitanceProbe-Edge_Cuts.dxf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]
2025-04-23 A bit of cleanup, updated readme
    [3214J-1-103E.stp, 694103107102.stp, LowCapacitanceProbe.kicad_pcb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]
